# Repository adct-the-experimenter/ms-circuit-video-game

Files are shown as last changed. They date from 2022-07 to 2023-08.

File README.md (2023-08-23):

# Mixed-Signal Circuit Video Games

## Move to new location: https://gitlab.com/pab44/ms-circuit-video-game

This is an ambitious project that will make a video game system from a hybrid computing approach.

The change was made from analog logic only to hybrid computing in order to give more options to developers.
 
The bidirectional communication between digital & hybrid controller module and analog module 
allows for 4 options: analog logic & digital rendering; parallel computation between analog module and 
digital module; analog computation as part of digital computation; analog and digital module used for 
partial computation for a personal computer. 

Includes collection of test circuits.

op-amp modeled in these circuits is LM358A.

#### The game circuits still need development. There is not a video signal output or audio signal output to the TV display yet.

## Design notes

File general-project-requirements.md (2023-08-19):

# MS Circuit Game System General Project Requirements

These are project requirements that are recommended for any game project
made based on this open-source project.

## Values provided to the user
- Video games that are able to be preserved through maintenance and repair of the circuitry
of the game system. 
- Modifiable games i.e. graphics, sound, and game logic can be modified by hardware or code.

## Requirements derived from values provided

### Circuit
- A functioning circuit schematic design validated by circuit simulation and/or models.
- Jumpers to allow hardware modification of the logic, graphics, sound of the game.

### PCB Design 
- Printed circuit board must be EMC (Electromagnetic compatibility) compliant.
- SMD jumpers to allow hardware modification of the logic, graphics, sound of the game.
- Test points for easy debug.
- Make pcb modules of the type pcb shield or pcb hat 
i.e. pcb that can be mounted to another pcb through connector.
For example, an raspberry pi hat connecting to a raspberry pi system pcb 
or Arduino shield connecting to an Arduino.

### Enclosure Form Factor
- Leave enough space for printed circuit board to fit.
- Make slots for the connectors for controllers and modifiable jumpers.
- Modular. Has holders that can hold

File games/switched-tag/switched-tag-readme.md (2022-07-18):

# Switched Tag

This game is basically reverse tag. In order to win, a player must become "It" and collide with the opposing player. 

A player becomes "It" by hitting the pendelum at its lowest point with a button press, 
the player who has been the closest to hitting the pendelum at its lowest point stays as the "It" player. 

## Controls 

Use joystick to move the character. 

Press pendelum hit button to hit pendelum and become "It".

Use switch to change between hitting pendelum at any point or hitting the pendelum at a constant low point.

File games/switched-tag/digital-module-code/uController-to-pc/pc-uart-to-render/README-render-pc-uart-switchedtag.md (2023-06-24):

# Switched Tag Render Module code

This is the personal computer side code that takes in digitized information on 
analog signals and interprets it into an image.

This is done with a USB UART bridge present on a stm32 microcontroller - or other microcontroller- 
that is used to communicate between microcontroller and PC

This specific render code is for switched tag.

## ADC UART Data Transfer Firmware
The firmware for read ADC values and transfering those values to PC over UART 
is located in console-hardware/render-module-hardware/uController-uart-pc-firmware.

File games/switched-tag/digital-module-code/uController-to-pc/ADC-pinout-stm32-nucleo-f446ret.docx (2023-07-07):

STM32 Nucleo-F446RE Pin to Signal

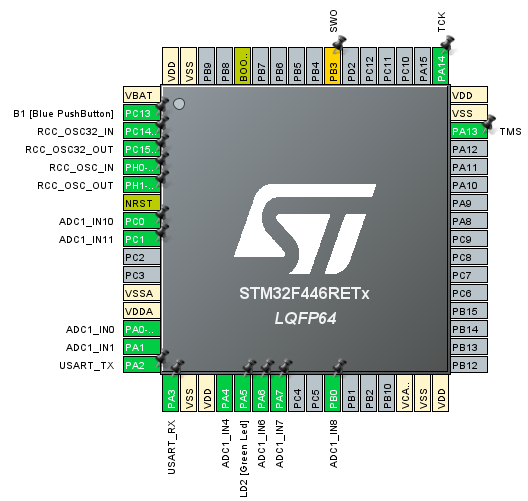
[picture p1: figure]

ADC1 Pinout and Channels

Buf_Idx - Channel - Pin ID - Board Pin

Buffer Index | ADC Input Channel | STM32 Pin ID | Board Pin | Signal
0 | In 0 | PA0 | A0 | P1X Buf
1 | In 1 | PA1 | A1 | P1Y Buf
2 | In 4 | PA4 | A2 | P2X Buf
3 | In 6 | PA6 | D12 | Collision Detect
4 | In 7 | PA7 | D11 | Pendulum
5 | In 8 | PB0 | A3 | P2Y Buf
6 | In 10 | PC0 | A5 | P2 It Buf
7 | In 11 | PC1 | A4 | P1 It Buf

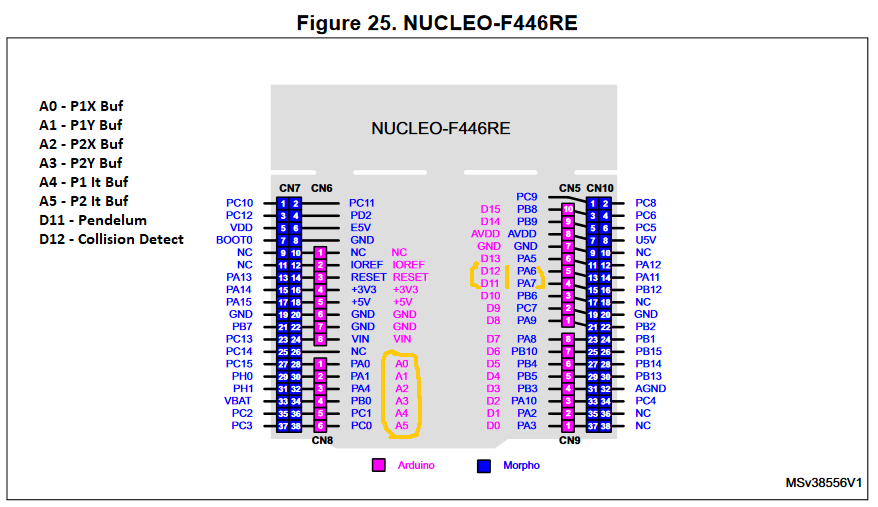
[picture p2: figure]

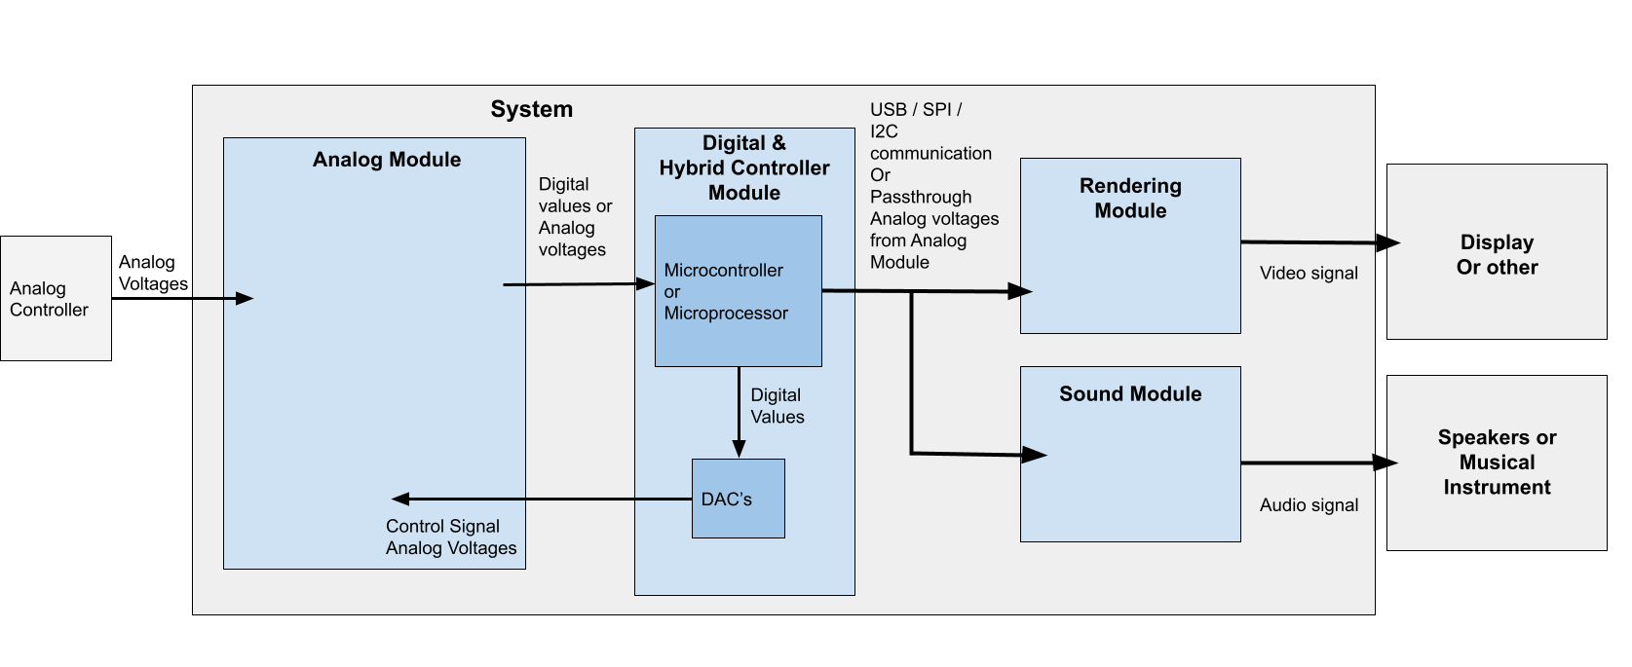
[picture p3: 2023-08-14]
general-system-block-diagram.png

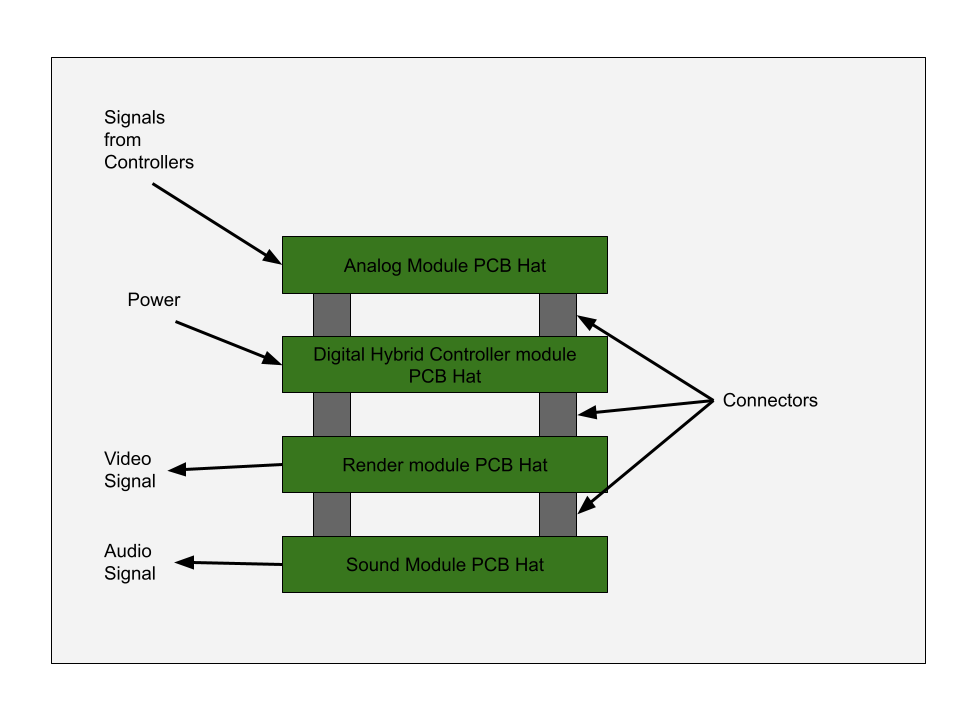
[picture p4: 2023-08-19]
Console-PCB-Hats-Diagram.png

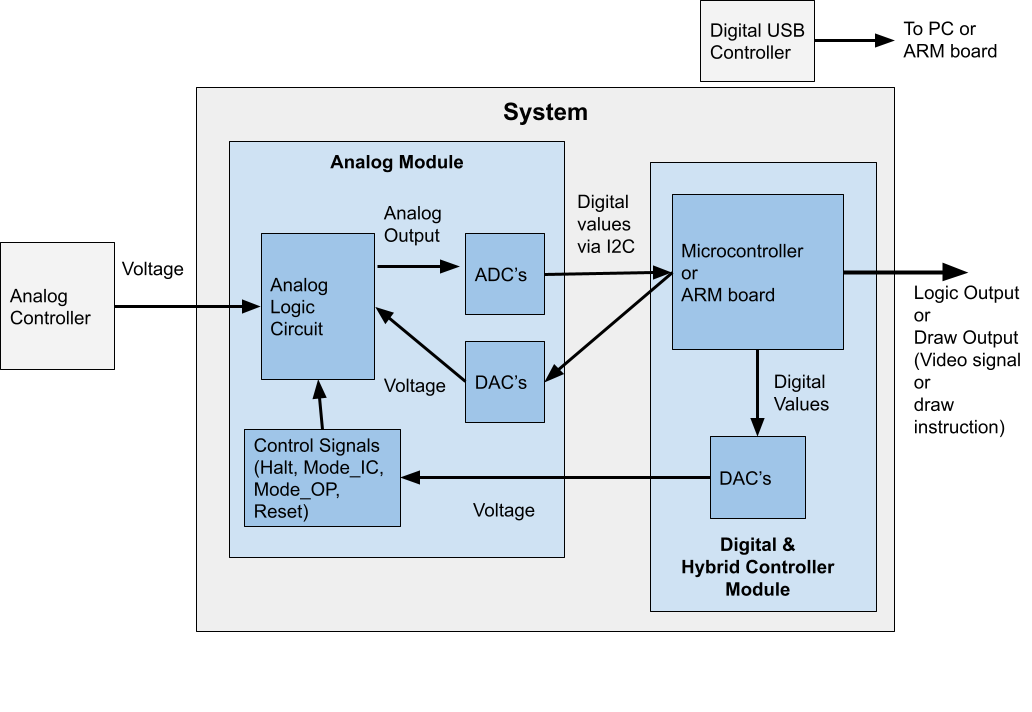
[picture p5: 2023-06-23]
system-block-diagram.png

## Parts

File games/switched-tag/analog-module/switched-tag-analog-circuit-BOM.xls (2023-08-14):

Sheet: Analog Module Parts - Breadboard Through Hole
 |  | Logic Circuit |  |  |  |  | Total Cost | $18.41
Total Cost of Module | $55.40 | Part Description | Mfr. | MPN | References | Unit Cost | Quantity | Cost | Vendor URL
 |  | 4 channel op-amp | Texas Instruments | TLV274IN | U1, U2, U3, U4, U5, U6, U7, U8, U9, U10, U11, U12, U13, U14, U15, U16, U17, U18, U19 | $0.50 | 6 | $2.98 | https://www.digikey.com/en/products/detail/texas-instruments/TLV274IN/530123
 |  | 1N914B diode | onsemi | 1N914B | D1, D2, D3, D4, D5, D6, D7, D8 | $0.10 | 8 | $0.80 | https://www.digikey.com/en/products/detail/onsemi/1N914B/978757
 |  | 100 nF / 0.1 uF capacitor | KEMET | R82EC3100AA70K | C1, C3, C4 | $0.28 | 3 | $0.84 | https://www.digikey.com/en/products/detail/kemet/R82EC3100AA70K/9685239
 |  | 100 pF capacitor |  | K101K10X7RF5UH5 | C2 | $0.25 | 1 | $0.25 | https://www.digikey.com/en/products/detail/vishay-beyschlag-draloric-bc-components/K101K10X7RF5UH5/2356746
 |  | 2.2 uF capacitor | KEMET | A759KK225M2EAAE685 | C5 | $1.24 | 1 | $1.24 | https://www.digikey.com/en/products/detail/kemet/A759KK225M2EAAE685/6196532
 |  | 5.1k resistor | Yageo | MBB0207VD5001BC100 | R13, R27 | $0.10 | 2 | $0.20 | https://www.digikey.com/en/products/detail/yageo/CFR-25JB-52-5K1/2236
 |  | 10k resistor | Yageo | CFR-12JB-52-10K | R1, R2, R3, R4, R5, R6, R7, R8, R9, R10, R11, R12, R14, R15, R16, R17, R18, R19, R20, R21, R22, R23, R24, R25, R26, R28, R29, R30, R31, R32, R33, R34, R35, R36, R37, R38, R40, R41 | $0.10 | 38 | $3.80 | https://www.digikey.com/en/products/detail/yageo/CFR25SJT-52-10K/9098847
 |  | 100k resistor | Stackpole Electronics | CF18JT100K | R39 | $0.10 | 1 | $0.10 | https://www.digikey.com/en/products/detail/yageo/CFR-25JT-52-100K/9098529
 |  | 1k resistor | Yageo | CFR-12JT-52-1K | R42, R43, R44 | $0.10 | 3 | $0.30 | https://www.digikey.com/en/products/detail/yageo/CFR-12JT-52-1K/9098047
 |  | N-channel mosfet | Microchip Tech. | TN0702N3-G | Q1, Q2, Q3, Q4, Q5 | $1.58 | 5 | $7.90 | https://www.digikey.com/en/products/detail/microchip-technology/tn0702n3-g/4902376
 |  | Power Supply Circuit (see MAX735CPA+ datasheet) |  |  |  |  | Total Cost | $36.99
 |  | Part Description | Mfr. | MPN | Unit Cost | Quantity | Cost | Vendor URL
 |  | MAX735CPA+ buck boost regulator negative voltage rail | Texas Instruments | MAX735CPA+ | $5.41 | 1 | $5.41 | https://www.digikey.com/en/products/detail/analog-devices-inc-maxim-integrated/MAX735CPA/1513835
 |  | 150 uF, 35V rated, aluminum electrolytic capacitor | EPCOS - TDK Electronics | B41866C7157M000 | $2.97 | 1 | $2.97 | https://www.digikey.com/en/products/detail/rubycon/100TXW150MEFC10X30/3133941
 |  | 470 uF, 10V rated, aluminum electrolytic capacitor | Rubycon | 35ZLJ470M10X16 | $0.81 | 1 | $0.81 | https://www.digikey.com/en/products/detail/rubycon/35ZLJ470M10X16/6182691
 |  | 2.2 uF capacitor | KEMET | A759KK225M2EAAE685 | $1.24 | 1 | $1.24 | https://www.digikey.com/en/products/detail/kemet/A759KK225M2EAAE685/6196532
 |  | 10 uF capacitor | KEMET | A758BG106M1EAAE070 | $0.48 | 5 | $2.40 | https://www.digikey.com/en/products/detail/kemet/A758BG106M1EAAE070/6196505
 |  | 82 pF capacitor | Murata Electronics | RCE5C1H820J0A2H03B | $0.46 | 1 | $0.46 | https://www.digikey.com/en/products/detail/murata-electronics/RCE5C1H820J0A2H03B/4277680
 |  | 3.3M resistor | Yageo | CFR-25JB-52-3M3 | $0.10 | 1 | $0.10 | https://www.digikey.com/en/products/detail/yageo/CFR-25JB-52-3M3/1458
 |  | 10 uH , 1 A rated inductor | Bourns Inc. | RLB0712-100KL | $0.45 | 1 | $0.45 | https://www.digikey.com/en/products/detail/bourns-inc/RLB0712-100KL/2561284
 |  | schottky diode 1n5817 | Diodes Incorporated | 1N5817-T | $0.39 | 1 | $0.39 | https://www.digikey.com/en/products/detail/diodes-incorporated/1N5817-T/22052
 |  | 3.3V LDO, 1.5A, 0.6V at 1.5A | Microchip Tech. | MCP1827-3302E/AT | $1.76 | 1 | $1.76 | https://www.digikey.com/en/products/detail/microchip-technology/MCP1827-3302E-AT/1223053
 |  | -3.3 LDO, 1.5A, 0.68V at 1.5A | Analog Devices Inc. | LT3015ET-3.3#PBF | $7.92 | 1 | $7.92 | https://www.digikey.com/en/products/detail/analog-devices-inc/LT3015ET-3-3-PBF/3024744
 |  | 5V power adapter 1 A, 10W | Tri-Mag LLC | L6R12H-050 | $12.06 | 1 | $12.06 | https://www.digikey.com/en/products/detail/tri-mag-llc/L6R12H-050/7682624
 |  | DC barrel connector | CUI Devices | PJ-006A | $1.02 | 1 | $1.02 | https://www.digikey.com/en/products/detail/cui-devices/PJ-006A/269296

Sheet: Analog Module Parts PCB SMD
Logic Circuit |  |  |  |  | Total Cost | $0.00
Part Description | Mfr. | MPN | References | Unit Cost | Quantity | Cost | Vendor URL
4 channel op-amp |  | TLV274IN | U13, U14, U15 |  | 3
1N914B diode |  | 1N914B | D1, D2, D3, D4, D5, D6, D7 |  | 7
1uF capacitor |  | R82EC3100AA70K | C3, C4 |  | 2
3.3 uF capacitor |  | K101K10X7RF5UH5 | C1, C2 |  | 2
5.1k resistor |  | MBB0207VD5001BC100 | R15, R16, R21 |  | 3
10k resistor |  | CFR-12JB-52-10K | R1, R2, R3, R4, R5, R6, R7, R8, R9, R10, R11, R12, R13, R14, R17, R18, R19, R20, R22, R25, R26, R27, R28, R29, R30, R31, R32, R33, R34, R35, R36 |  | 31
100k resistor |  | CF18JT100K | R23, R24 |  | 2
1k resistor |  | CFR-12JT-52-1K | R37, R38 |  | 2
N-channel mosfet |  | TN0702N3-G | Q1, Q2 |  | 2

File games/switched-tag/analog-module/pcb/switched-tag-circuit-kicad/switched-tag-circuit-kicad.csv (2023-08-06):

Source: | /home/pab/niche-engineer-proj/analog-circuit-game-console/ms-circuit-video-games/games/switched-tag/analog-module/pcb/switched-tag-circuit-kicad/switched-tag-circuit-kicad.kicad_sch
Date: | Sat Aug 5 21:38:33 2023
Tool: | Eeschema 7.0.6
Generator: | /usr/share/kicad/plugins/bom_csv_grouped_by_value.py
Component Count: | 62
Collated Components:
Item | Qty | Reference(s) | Value | LibPart | Footprint | Datasheet | DNP | Sim.Device | Sim.Enable | Sim.Library | Sim.Name | Sim.Params | Sim.Pins | Sim.Type | Spice_Netlist_Enabled | Spice_Primitive
1 | 2 | C1, C2 | 3.3u | Device:C | Capacitor_SMD:C_0603_1608Metric | ~
2 | 2 | C3, C4 | 1u | Device:C | Capacitor_SMD:C_0603_1608Metric | ~
3 | 7 | D1, D2, D3, D4, D5, D6, D7 | D1N914 | Device:D | Diode_SMD:D_0603_1608Metric | 1n914 |  |  |  | ${SPICE_MODEL_DIR_REL}/1N914.lib | D1N914 |  | 2=1 1=2
4 | 2 | Q1, Q2 | RUL035N02 | Device:Q_NMOS_DGS | Package_TO_SOT_SMD:SOT-89-5 | ~ |  |  |  | ${SPICE_MODEL_DIR_REL}/rul035n02.lib | RUL035N02 |  | 1=1 2=2 3=3
5 | 31 | R1, R2, R3, R4, R5, R6, R7, R8, R9, R10, R11, R12, R13, R14, R17, R18, R19, R20, R22, R25, R26, R27, R28, R29, R30, R31, R32, R33, R34, R35, R36 | 10k | Device:R | Resistor_SMD:R_0603_1608Metric | ~
6 | 3 | R15, R16, R21 | 5k | Device:R | Resistor_SMD:R_0603_1608Metric | ~
7 | 2 | R23, R24 | 100k | Device:R | Resistor_SMD:R_0603_1608Metric | ~
8 | 2 | R37, R38 | 1k | Device:R | Resistor_SMD:R_0603_1608Metric | ~
9 | 3 | U13, U14, U15 | TLV9154IDR | switched-tag-symbol-lib:TLV9154IDR | switched-tag-footprint-lib:SOIC_9154IDR_TEX | TLV9154IDR |  |  | 0
10 | 1 | V1 | VSIN | Simulation_SPICE:VSIN |  | ~ |  | V |  |  |  | dc=1.5 ampl=1.5 f=10 ac=1 | 1=+ 2=- | SIN
11 | 2 | V2, V3 | VPULSE | Simulation_SPICE:VPULSE |  | ~ |  | V |  |  |  | y1=0 y2=1 td=0.15 tr=2m tf=2m tw=0.5 per=1 | 1=+ 2=- | PULSE
12 | 1 | V4 | -3.3 | Simulation_SPICE:VDC |  | ~ |  | V |  |  |  |  | 1=+ 2=- | DC
13 | 1 | V5 | 3.3 | Simulation_SPICE:VDC |  | ~ |  | V |  |  |  |  | 1=+ 2=- | DC
14 | 3 | V6, V7, V8 | 1 | Simulation_SPICE:VDC |  | ~ |  | V |  |  |  |  | 1=+ 2=- | DC

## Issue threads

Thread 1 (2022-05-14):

Kicad simulation results do not match LTSpice

adct-the-experimenter, 2022-05-14:
Kicad simulation uses a different component for now, since the lm358 generic spice models do not work as well
compared to LM358 ltspice model.

adct-the-experimenter, 2023-07-17:
For this project, LTSpice is primarily used for simulation. KiCAD is primarily used for producing the pcb, but KiCAD simulation is helpful for checking that the correct circuit is printed.

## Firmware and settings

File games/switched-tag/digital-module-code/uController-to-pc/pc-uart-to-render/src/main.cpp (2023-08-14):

// C library headers
#include <cstdio>
#include <cstring>
#include <string>


#include <libserial/SerialPort.h>

#include <cstdlib>
#include <iostream>
#include <unistd.h>
#include <bitset>

#include <signal.h> //for signal interrupt


#include "raylib.h" //for drawing 

//for thread handling
#include <thread>
#include <mutex>
#include <atomic>

#include "moving_average.h"

#define USING_DEBUG

//variable used to indicate that program needs to quit
//made atomic because it needs to be updated in main thread and adc update buffer thread
static std::atomic<bool> g_quitProgram;


// Handler for SIGINT, caused by
// Ctrl-C at keyboard
void handle_sigint(int sig)
{
	g_quitProgram.store(true);
    printf("Caught interrupt signal, signal %d\n", sig);
}	

//the serial port that will host UART and PC communication
LibSerial::SerialPort serial_port;
const char* const SERIAL_PORT_1 = "/dev/ttyACM0" ;


//function to initialize communication between UART and PC
//returns bool indicating if initialization was successful or not.
bool init_UART_PC_comm();

enum class ReaderState { STARTING_READ=0, READING_ADC_CHANNEL, READING_ADC_VALUE, READ_DONE };

//function to read value from UART serial port
void read_adc_value_from_UART(uint16_t* adc_val_ptr, uint8_t* adc_buf_index_ptr, size_t* ms_timeout,
							  char* read_buf_adc_val_ptr, uint8_t* read_buf_adc_val_index_ptr, 
							  ReaderState* reader_state_ptr);


//function to initialize raylib
bool InitRaylib();
void CloseRaylib();

const int screenWidth = 800;
const int screenHeight = 450;
void render();

#define NUM_ADC_INPUTS 8

#define ADC_MAX_VAL 4095
#define ADC_MIN_VAL 0

enum class ADC_Channel : uint8_t {P1X=0, P1Y, P2X, CD, PD, P2Y, P2_IT, P1_IT };
float adc_channel_info[NUM_ADC_INPUTS] = {0,0,0,0,0,0,0,0};


//for granting exclusive access to adc buffer
std::mutex mutex_adc_buf;

//function to update adc buffer
void UpdateADCBuffer();

void UpdateADCBuffer()
{
	// Allocate memory for read buffer, set size according to your needs
	char read_buf_adc_val[100];
	uint8_t read_buf_adc_val_index = 0;
	memset(&read_buf_adc_val, '\0', sizeof(read_buf_adc_val));
	
	//set up state machine for reading adc channel and value and matching channel to value.
	ReaderState reader_state = ReaderState::STARTING_READ;	
	
	uint16_t adc_val = 0;
	uint8_t adc_channel = 0;
	
	// Specify a timeout value (in milliseconds) for UART communication.
	size_t ms_timeout = 250;
	
	//bitset to keep track of which channels have been updated
	std::bitset <NUM_ADC_INPUTS> updated_channels_bitset;
	updated_channels_bitset.reset();
	
	//second buffer to transfer data to main adc buffer
	float temp_adc_buf[NUM_ADC_INPUTS] = {0,0,0,0,0,0,0,0};
	
	//loop forever
	while(true)
	{
		//if quit program is true, then break out of this loop
		if(g_quitProgram.load()){break;}
		
		//read adc channel and value from UART
		read_adc_value_from_UART(&adc_val,&adc_channel,&ms_timeout,
								&read_buf_adc_val[0], &read_buf_adc_val_index,
								&reader_state);
		
		
		 //if adc read done, upate temporary buffer and bitset
		if(reader_state == ReaderState::READ_DONE)
		{	 
			 temp_adc_buf[adc_channel] = (float)adc_val;
			 updated_channels_bitset.set(adc_channel);	 
		}
		 
		
		//update adc buffer if all channels in temporary buffer have been updated.
		if(updated_channels_bitset.all())
		{
			//printf("All channels updated! buffer update unlocked.");
			//put lock on adc buffer to update it
			//critical section
			mutex_adc_buf.lock();
			
			for(int i = 0; i < NUM_ADC_INPUTS; i++)
			{
				adc_channel_info[i] = temp_adc_buf[i];
			}
			
			//unlock adc buffer 
			mutex_adc_buf.unlock();
			
			updated_channels_bitset = 0; 
			
		}
	}
	
	
	
}


int main() {
	
	int num_concurrent_threads = std::thread::hardware_concurrency();
	std::cout << "The number of concurrent threads is " << num_concurrent_threads << "\n";
	
	//if pc does not have at least 2 concurrent threads, exit program
	if(num_concurrent_threads < 2)
	{
		printf("Error! Need CPU with 2 or more concurrent threads to run this program.");
		return -1;
	}
  
	if(!InitRaylib())
	{
		printf("Failed to initialize raylib!\n");
		return -1;
	}
  
	//if initialization of UART PC communication fails, exit program
	if(!init_UART_PC_comm())
	{
	  printf("Failed to initialize PC UART communication!\n");
	  return -1;
	}
	
	//start thread to update adc buffer
	std::thread adc_buf_reader(&UpdateADCBuffer);
	
	g_quitProgram.store(false);
	
	signal(SIGINT, handle_sigint);
	
	while (!g_quitProgram.load())
	{	    
	    //draw stuff.
	    render();   
	}
	
	CloseRaylib();
	
	adc_buf_reader.join();
	
	return 0; // success
  
};

void CloseRaylib()
{
	 CloseWindow(); 
}

#define USE_MOVING_AVERAGE

#define MOV_AVG_PERIOD 6
MovingAverage mavg_p1x(MOV_AVG_PERIOD);
MovingAverage mavg_p1y(MOV_AVG_PERIOD);
MovingAverage mavg_p2x(MOV_AVG_PERIOD);
MovingAverage mavg_p2y(MOV_AVG_PERIOD);

const float circle_size = 10.0f;

void render()
{
	//P1X=0, P1Y, P2X, CD, PD, P2Y, P2_IT, P1_IT
	
	if(WindowShouldClose()){g_quitProgram.store(true);}
	
	float p1x, p1y, p2x, p2y, collision_detect;
	
	//put lock on adc buffer to read from it without buffer being updated during read
	//if not locked, block until mutex is available for use
	//perform all reads from adc in one section
	//critical section 
	mutex_adc_buf.lock();
	
	p1x = adc_channel_info[static_cast<int>(ADC_Channel::P1X)];
	p1y = adc_channel_info[static_cast<int>(ADC_Channel::P1Y)];
	p2x = adc_channel_info[static_cast<int>(ADC_Channel::P2X)];
	p2y = adc_channel_info[static_cast<int>(ADC_Channel::P2Y)];
	collision_detect = adc_channel_info[static_cast<int>(ADC_Channel::CD)];
	
	//unlock adc buffer, let it be updated
	mutex_adc_buf.unlock();
	
	#ifdef USING_DEBUG
	char str[80];
	
	//DrawText(const char *text, int posX, int posY, int fontSize, Color color);
	sprintf(str, "adc[p1x]: %f", adc_channel_info[static_cast<int>(ADC_Channel::P1X)]);
	DrawText(str, 0, 0, 12, BLACK);

	sprintf(str, "adc[p1y]: %f " , adc_channel_info[static_cast<int>(ADC_Channel::P1Y)] );
	DrawText(str, 0, 20, 12, BLACK);
	
	sprintf(str, "adc[p2x]: %f " , adc_channel_info[static_cast<int>(ADC_Channel::P2X)] );
	DrawText(str, 0, 40, 12, BLACK);
	
	sprintf(str, "adc[p2y]: %f " , adc_channel_info[static_cast<int>(ADC_Channel::P2Y)] );
	DrawText(str, 0, 60, 12, BLACK);
	
	sprintf(str, "adc[p1_it]: %f " , adc_channel_info[static_cast<int>(ADC_Channel::P1_IT)] );
	DrawText(str, 0, 80, 12, BLACK);
	
	sprintf(str, "adc[p2_it]: %f " , adc_channel_info[static_cast<int>(ADC_Channel::P2_IT)] );
	DrawText(str, 0, 100, 12, BLACK);
	
	sprintf(str, "adc[cd]: %f " , adc_channel_info[static_cast<int>(ADC_Channel::CD)] );
	DrawText(str, 0, 120, 12, BLACK);
	
	sprintf(str, "adc[pd]: %f " , adc_channel_info[static_cast<int>(ADC_Channel::PD)] );
	DrawText(str, 0, 140, 12, BLACK);
	#endif
	
	//convert to screen coordinates
	//reverse x coordinates because joystick direction is inversely proportional to adc value
	p1x = ( p1x / (float)(ADC_MAX_VAL - ADC_MIN_VAL) )*screenWidth;
	
	#ifdef USE_MOVING_AVERAGE
	mavg_p1x.addData(p1x);
	p1x = mavg_p1x.getMean();
	#endif
	
	p1y = screenHeight - ( p1y / (float)(ADC_MAX_VAL - ADC_MIN_VAL) )*screenHeight;
	
	#ifdef USE_MOVING_AVERAGE
	mavg_p1y.addData(p1y);
	p1y = mavg_p1y.getMean();
	#endif
	
	p2x = ( p2x / (float)(ADC_MAX_VAL - ADC_MIN_VAL) )*screenWidth;
	
	#ifdef USE_MOVING_AVERAGE
	mavg_p2x.addData(p2x);
	p2x = mavg_p2x.getMean();
	#endif
	
	p2y = screenHeight - ( p2y / (float)(ADC_MAX_VAL - ADC_MIN_VAL) )*screenHeight;
	
	#ifdef USE_MOVING_AVERAGE
	mavg_p2y.addData(p2y);
	p2y = mavg_p2y.getMean();
	#endif
	
	Vector2 p1Position = { p1x, p1y};
	Vector2 p2Position = { p2x, p2y};
	
	//set color based on collision detect event
	Color p1_color = RED;
	Color p2_color = BLUE;
	
	if(collision_detect > 3000)
	{
		p1_color = YELLOW;
		p2_color = YELLOW;
	}
	
	//set size based on which player is it.
	float p1_size_mod = 0.02 * adc_channel_info[static_cast<int>(ADC_Channel::P1_IT)];
	float p2_size_mod = 0.02 * adc_channel_info[static_cast<int>(ADC_Channel::P2_IT)];

	BeginDrawing();

    ClearBackground(RAYWHITE);

    DrawCircleV(p1Position, circle_size + p1_size_mod, p1_color);
    
    DrawCircleV(p2Position, circle_size + p2_size_mod, p2_color);
    

    EndDrawing();
}



void read_adc_value_from_UART(uint16_t* adc_val_ptr, uint8_t* adc_channel_ptr, size_t* ms_timeout,
							  char* read_buf_adc_val_ptr, uint8_t* read_buf_adc_val_index_ptr,
							  ReaderState* reader_state_ptr)
{
	// Wait for data to be available at the serial port.
	while(!serial_port.IsDataAvailable()) 
	{
		//make thread sleep for 1000 microseconds instead of whole CPU program
		//read_adc_value_from_UART function is in use in adc buffer update thread
		 std::this_thread::sleep_for(std::chrono::microseconds(1000));
	}


	// Char variable to store data coming from the serial port.
	char data_byte;
	
	
	// Read one byte from the serial port and print it to the terminal.
	try
	{
		// Read a single byte of data from the serial port.
		serial_port.ReadByte(data_byte, *ms_timeout) ;
	}
	catch (const LibSerial::ReadTimeout&)
	{
		std::cerr << "\nThe ReadByte() call has timed out." << std::endl ;
	}
	
	
	// Show the user what is being read from the serial port.
	//std::cout << data_byte;
	
	switch(*reader_state_ptr)
	{
		case ReaderState::STARTING_READ:
		{
			//if space character found, then skip and wait for \n
			if(data_byte == ' ')
			{
				//reset buffer adc val index
				*read_buf_adc_val_index_ptr = 0;
				
				//do nothing
			}
			else if(data_byte == '\n')
			{
				//change state to reading adc channel
				*reader_state_ptr = ReaderState::READING_ADC_CHANNEL;
			}
			break;
		}
		case ReaderState::READING_ADC_CHANNEL:
		{
			switch(data_byte)
			{
				case '0':{*adc_channel_ptr = 0; break;}
				case '1':{*adc_channel_ptr = 1; break;}
				case '2':{*adc_channel_ptr = 2; break;}
				case '3':{*adc_channel_ptr = 3; break;}
				case '4':{*adc_channel_ptr = 4; break;}
				case '5':{*adc_channel_ptr = 5; break;}
				case '6':{*adc_channel_ptr = 6; break;}
				case '7':{*adc_channel_ptr = 7; break;}
			}
			
			//if space character found
			if(data_byte == ' ')
			{
				//reset buffer adc val index
				*read_buf_adc_val_index_ptr = 0;
				
				//change state to reading adc value
				*reader_state_ptr = ReaderState::READING_ADC_VALUE;
			}
			//if \n character found
			else if(data_byte == '\n')
			{
				//do nothing.
			}  
			
			break;
		}
		case ReaderState::READING_ADC_VALUE:
		{
			read_buf_adc_val_ptr[*read_buf_adc_val_index_ptr] = data_byte;
			*read_buf_adc_val_index_ptr = *read_buf_adc_val_index_ptr + 1;
			
			//if space character found, then skip and wait for \n
			if(data_byte == ' ')
			{
				//do nothing
			}
			//if \n character found 
			else if(data_byte == '\n')
			{
				
				//convert chars in read buf to integer and store it
				*adc_val_ptr = atoi(read_buf_adc_val_ptr);
				
				//change state to read done
				*reader_state_ptr = ReaderState::READ_DONE;
			}
			  
			break;
		}
		case ReaderState::READ_DONE:
		{
			//std::cout << "adc channel: " << uint(*adc_channel_ptr) << ", adc value: " << *adc_val_ptr << "\n";
			*reader_state_ptr = ReaderState::READING_ADC_CHANNEL;
			break;
		}
	}
}


bool init_UART_PC_comm()
{
	try
    {
        // Open the Serial Port at the desired hardware port.
        serial_port.Open(SERIAL_PORT_1) ;
    }
    catch (const LibSerial::OpenFailed&)
    {
        std::cerr << "The serial port did not open correctly." << std::endl ;
        return false;
    }

    // Set the baud rate of the serial port.
    serial_port.SetBaudRate(LibSerial::BaudRate::BAUD_115200) ;

    // Set the number of data bits.
    serial_port.SetCharacterSize(LibSerial::CharacterSize::CHAR_SIZE_8) ;

    // Turn off hardware flow control.
    serial_port.SetFlowControl(LibSerial::FlowControl::FLOW_CONTROL_NONE) ;

    // Disable parity.
    serial_port.SetParity(LibSerial::Parity::PARITY_NONE) ;
    
    // Set the number of stop bits.
    serial_port.SetStopBits(LibSerial::StopBits::STOP_BITS_1) ;
    
    return true;
}


bool InitRaylib()
{
	

    InitWindow(screenWidth, screenHeight, "Switched Tag Rendering Window");

    SetTargetFPS(60);               // Set our game to run at 60 frames-per-second
    
    return true;
}

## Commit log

2022-03-27 First starting tracking this project. Some circuits adapted from previous stabber project.
2022-03-28 Updated circuits to use lower resistor values. Updated collision detector 1d to use improved zero crossing detector.
2022-03-28 Updated summer to use smaller resistor values.
2022-03-29 Added sample and hold test circuit.
2022-03-30 Working on circuit for game of tag with a twist.
2022-03-30 Added a win determination circuit.
2022-03-31 Started work on switched-tag logic. Need to finish and debug.
2022-03-31 Changed pendelum model to triangle wave. Fixed related issues with pendelum in game circuit.
2022-04-02 Made fixes to sample and hold circuit.
2022-04-02 Updated switched tag game to model sample and hold used for drawing.
2022-04-05 Removed sample and hold circuit from switched-tag b/c ADC include sample and hold.
2022-04-07 Added readme for switched-tag game.
2022-04-09 Lowered value of supply voltage and also signal range to fit common 3.3V logic level.
2022-04-18 Added BOM and changed nmos used for sample & hold and it determination circuit.
    [switched-tag-analog-circuit-BOM.xls]
2022-04-24 Fixed problems with it player determination circuit in switched tag game.
    [switched-tag-analog-circuit-BOM.xls]
2022-04-29 Started transferring circuit to KiCAD.
    [switched-tag-abs-zero-detector.kicad_sch, switched-tag-circuit-kicad.kicad_pcb, switched-tag-circuit-kicad.kicad_sch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]
2022-05-07 Saving progress on kicad schematic. Trying to set up ngspice simulation.
    [switched-tag-abs-zero-detector.kicad_sch, switched-tag-circuit-kicad.kicad_sch, switched-tag-collision-detection.kicad_sch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]
2022-05-07 Have kicad simulation working. Need to debug pendelum of kicad circuit and it player determination.
    [switched-tag-circuit-kicad.kicad_sch]
2022-05-08 Fixed problems with kicad circuit adn spice setup.
    [switched-tag-abs-zero-detector.kicad_sch, switched-tag-circuit-kicad.kicad_sch, switched-tag-collision-detection.kicad_sch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]
2022-05-12 Changed spice model of opamp in kicad sim. Fixed design error in it player determination in ltspice and kicad schematic
    [lmx58_lm2904.dsn, switched-tag-abs-zero-detector.kicad_sch, switched-tag-circuit-kicad.kicad_sch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]
2022-05-14 Updated kicad circuit. The kicad sim and ltspice do not match up well. Need to fix.
    [switched-tag-abs-zero-detector.kicad_sch, switched-tag-circuit-kicad.kicad_sch, switched-tag-it-player-determination-circuit.kicad_sch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]
2022-05-16 Added some prep work for console hardware.
    [ms-circuit-system-console-base-circuit.kicad_pcb, ms-circuit-system-console-base-circuit.kicad_sch, switched-tag-abs-zero-detector.kicad_sch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]
2022-05-23 Saving progress.
    [switched-tag-abs-zero-detector.kicad_sch, switched-tag-collision-detection.kicad_sch, switched-tag-it-player-determination-circuit.kicad_sch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]
2022-05-23 Changed names of folders.
    [switched-tag-abs-zero-detector.kicad_sch, switched-tag-analog-circuit-BOM.xls, switched-tag-circuit-kicad.kicad_pcb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]
2022-05-23 Cleanup of renamed directories.
    [switched-tag-abs-zero-detector.kicad_sch, switched-tag-analog-circuit-BOM.xls, switched-tag-circuit-kicad.kicad_pcb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]
2022-05-26 Removed unused converter in switched tag.
2022-06-20 Changed circuit. Previous circuit did not accurately detect collision due to polarity issues.
2022-06-20 Moved kicad sim circuit to new folder to set it apart from pcb circuit.
    [switched-tag-abs-zero-detector.kicad_sch, switched-tag-circuit-kicad.csv, switched-tag-circuit-kicad.kicad_pcb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]
2022-06-20 Cleanup. Kicad file move.
    [switched-tag-abs-zero-detector.kicad_sch, switched-tag-circuit-kicad.kicad_pcb, switched-tag-circuit-kicad.kicad_sch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]
2022-07-18 Updated circuit. Added another option to become it player to prevent stalemate.
2022-07-18 Updated README for switched tag.
2023-06-19 Added new code that renders based on information passed from UART.
2023-06-19 Managed to implement adc channel and value extraction from uart serial data.
2023-06-19 Abstracted adc channel and reading code to function.
2023-06-19 Aaving progress. Need to fix drawing frame rate and data acquisition.
    [main.cpp]
2023-06-20 Added thread and mutex to update adc buffer. Rendering works well now at 60 FPS frame rate.
2023-06-21 Implemented moving average to smooth out movement caused by analog variation due to noise.
    [main.cpp]
2023-06-23 Updating several files. Added firmware code for stm32 ADC UART data transfer.
    [switched-tag-analog-circuit-BOM.xls]
2023-06-24 Updated some files and folder names
    [usb-to-pc-graphics-render-circuit.kicad_pcb, usb-to-pc-graphics-render-circuit.kicad_sch]
2023-06-27 Updated changes made in adc uart data transfer git project.
2023-07-07 Added document showing stm32f446ret to circuit connections.
2023-07-17 Updated .gitignore.
    [switched-tag-abs-zero-detector.kicad_sch, switched-tag-circuit-kicad.csv, switched-tag-circuit-kicad.kicad_pcb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]
2023-07-17 Converted Lm358.mod to .lib file for convenience.
    [switched-tag-circuit-kicad.kicad_sch, switched-tag-collision-detection.kicad_sch, switched-tag-it-player-determination-circuit.kicad_sch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]
2023-07-17 Updated kicad circuit to match LTSpice circuit.
2023-07-17 Removed unused files.
    [switched-tag-circuit-kicad.csv, switched-tag-pendelum-model-alt.kicad_sch, switched-tag-pendelum-model.kicad_sch]
2023-07-24 Updated simulation schematic. Need to fix timestep too small problem.
    [switched-tag-circuit-kicad.kicad_pcb, switched-tag-circuit-kicad.kicad_sch, switched-tag-collision-detection.kicad_sch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]
2023-07-24 Fixed timestep too small prblem. Pulse signal was very short.
    [switched-tag-circuit-kicad.kicad_sch]
2023-07-24 Forgot to add custom kicad library.
2023-07-30 Started pcb with placeholder components. Incomplete PCB.
    [switched-tag-analog-circuit-BOM.xls, switched-tag-circuit-kicad.kicad_pcb, switched-tag-collision-detection.kicad_sch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]
2023-08-06 Saving pcb placement.
    [switched-tag-circuit-kicad.csv, switched-tag-circuit-kicad.kicad_pcb, switched-tag-circuit-kicad.kicad_sch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]
2023-08-06 Changed component size from 0603 to 0805 for easier hand soldering.
    [switched-tag-circuit-kicad.kicad_pcb, switched-tag-collision-detection.kicad_sch, switched-tag-it-player-determination-circuit.kicad_sch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]
2023-08-14 Added new block diagram and general requirements.
    [switched-tag-analog-circuit-BOM.xls, switched-tag-circuit-kicad.kicad_pcb]
2023-08-19 Added to general requirements. Added new diagram showing pcb hats.
